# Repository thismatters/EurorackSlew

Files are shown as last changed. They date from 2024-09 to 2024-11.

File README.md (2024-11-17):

# Gated Slew

Causes V/Oct signals to gradually change between voltages with either a linear or logrithmic profile, can work on upward changes in voltage, downward, or both. Slew rate is set with knob. Gate controls whether slew is applied or not.

The circuit here is based on the [Yusynth gated slew](https://yusynth.net/Modular/EN/DUALSLEW/index.html) with minor tweaks to make it more Eurorack friendly. The changes I've made are thus:
* Selected resistors appropriate for +/-12V rails,
* Added polarity protection so that a backward power header doesn't fry anything (twin series schotty diodes: BAT54SL),
* Full surface mount design.

The Yusynth page is a treasure trove of information about this circuit that I am too amateur to claim as my own; please read that outstanding page before using this circuit. The page provides many details and other implementations of this circuit that you may find suitable.

The KiCAD project here uses the library/footprints [found in my companion repo](https://github.com/thismatters/EurorackKiCAD).

## Width

12hp on an Intellijel 1U rack.

## Inputs

Jacks for:
- V/Oct which will be slewed,
- Gate to control when slew occurs (default is always).

Knob for slew rate.

Switches for
- Linear or logrithmic slew,
- Slew on rising edge (up), falling edge (down), or both (middle).

## Outputs

Jack for V/Oct.

LED to indicate when gate is active.

## Vendors

There are part numbers in the [BOM](slew.csv) for many of the parts (not for basic passives though) at the following vendors:

* [Mouser](https://www.mouser.com): Needs no introduction. Get your ICs from here (or [digikey](https://www.digikey.com)).
* [Tayda Electronics](https://www.taydaelectronics.com/): Good supplier for passive components; audio jacks, and potentiometers. Their audio jacks are slightly smaller than the thonkiconn from thonk.
* [Love My Switches](https://lovemyswitches.com/): Has [really good knobs](https://lovemyswitches.com/anodized-aluminum-knob-the-lo-fi-1-4-smooth-shaft-12-5mm-od/) to go on those potentiometers!
* [OSHPark](https://oshpark.com/): Fast and (relatively) cheap PCB manufacturer. The [V0 circuit](https://oshpark.com/shared_projects/VN6XGUSn) works really well.

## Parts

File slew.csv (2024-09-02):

# | Reference | Qty | Value | Footprint | DNP | Vendor | PartNum
1 | C1, C2 | 2 | 22u 50V | Capacitor_THT:CP_Radial_D5.0mm_P2.50mm
2 | C3 | 1 | 100n | Capacitor_SMD:C_0805_2012Metric
3 | C4 | 1 | 680n box | Capacitor_THT:C_Rect_L7.2mm_W4.5mm_P5.00mm_FKS2_FKP2_MKS2_MKP2
4 | D1, D2 | 2 | BAT54S | Package_TO_SOT_SMD:SOT-23 |  | Mouser | 863-BAT54SLT1G
5 | D3, D4, D5, D6 | 4 | 1N4148 | Diode_SMD:D_SOD-323_HandSoldering
6 | D7 | 1 | LED_GREEN | LED_THT:LED_D3.0mm
7 | J1 | 1 | Conn_02x05_Odd_Even | Eurorack:PinHeader_2x05_P2.54mm_Vertical |  | Tayda | A-2939
8 | J2, J3, J4 | 3 | AudioJack2_SwitchT | Eurorack:AudioJack2_Tayda_A-2566 |  | Tayda | A-2566
9 | Q1 | 1 | MMBF4393 | Package_TO_SOT_SMD:SOT-23 |  | Mouser | 863-MMBF4393LT1G
10 | Q2 | 1 | MMBF170 | Package_TO_SOT_SMD:SOT-23 |  | Mouser | 863-MMBF170LT1G
11 | R1, R2, R5 | 3 | 10 | Resistor_SMD:R_0805_2012Metric
12 | R3, R8, R10 | 3 | 120K | Resistor_SMD:R_0805_2012Metric
13 | R4 | 1 | 1M | Resistor_SMD:R_0805_2012Metric
14 | R6 | 1 | 470 | Resistor_SMD:R_0805_2012Metric
15 | R7 | 1 | 2.2M | Resistor_SMD:R_0805_2012Metric
16 | R9 | 1 | 12K | Resistor_SMD:R_0805_2012Metric
17 | R11 | 1 | 1K | Resistor_SMD:R_0805_2012Metric
18 | RV1 | 1 | A1M | Eurorack:Potentiometer_RV16AF-41-15R1 |  | Tayda | A-2425
19 | SW1 | 1 | SW_DPDT_x2 | Eurorack:Switch_DPDT_Tayda_A-5752 |  | Tayda | A-6809
20 | SW2 | 1 | SW_SPDT_MSM | Eurorack:Switch_SPDT_Tayda_A-5751 |  | Tayda | A-5671
21 | U1 | 1 | TL074 | Package_SO:SOIC-14_3.9x8.7mm_P1.27mm |  | Mouser | 595-TL074CDR

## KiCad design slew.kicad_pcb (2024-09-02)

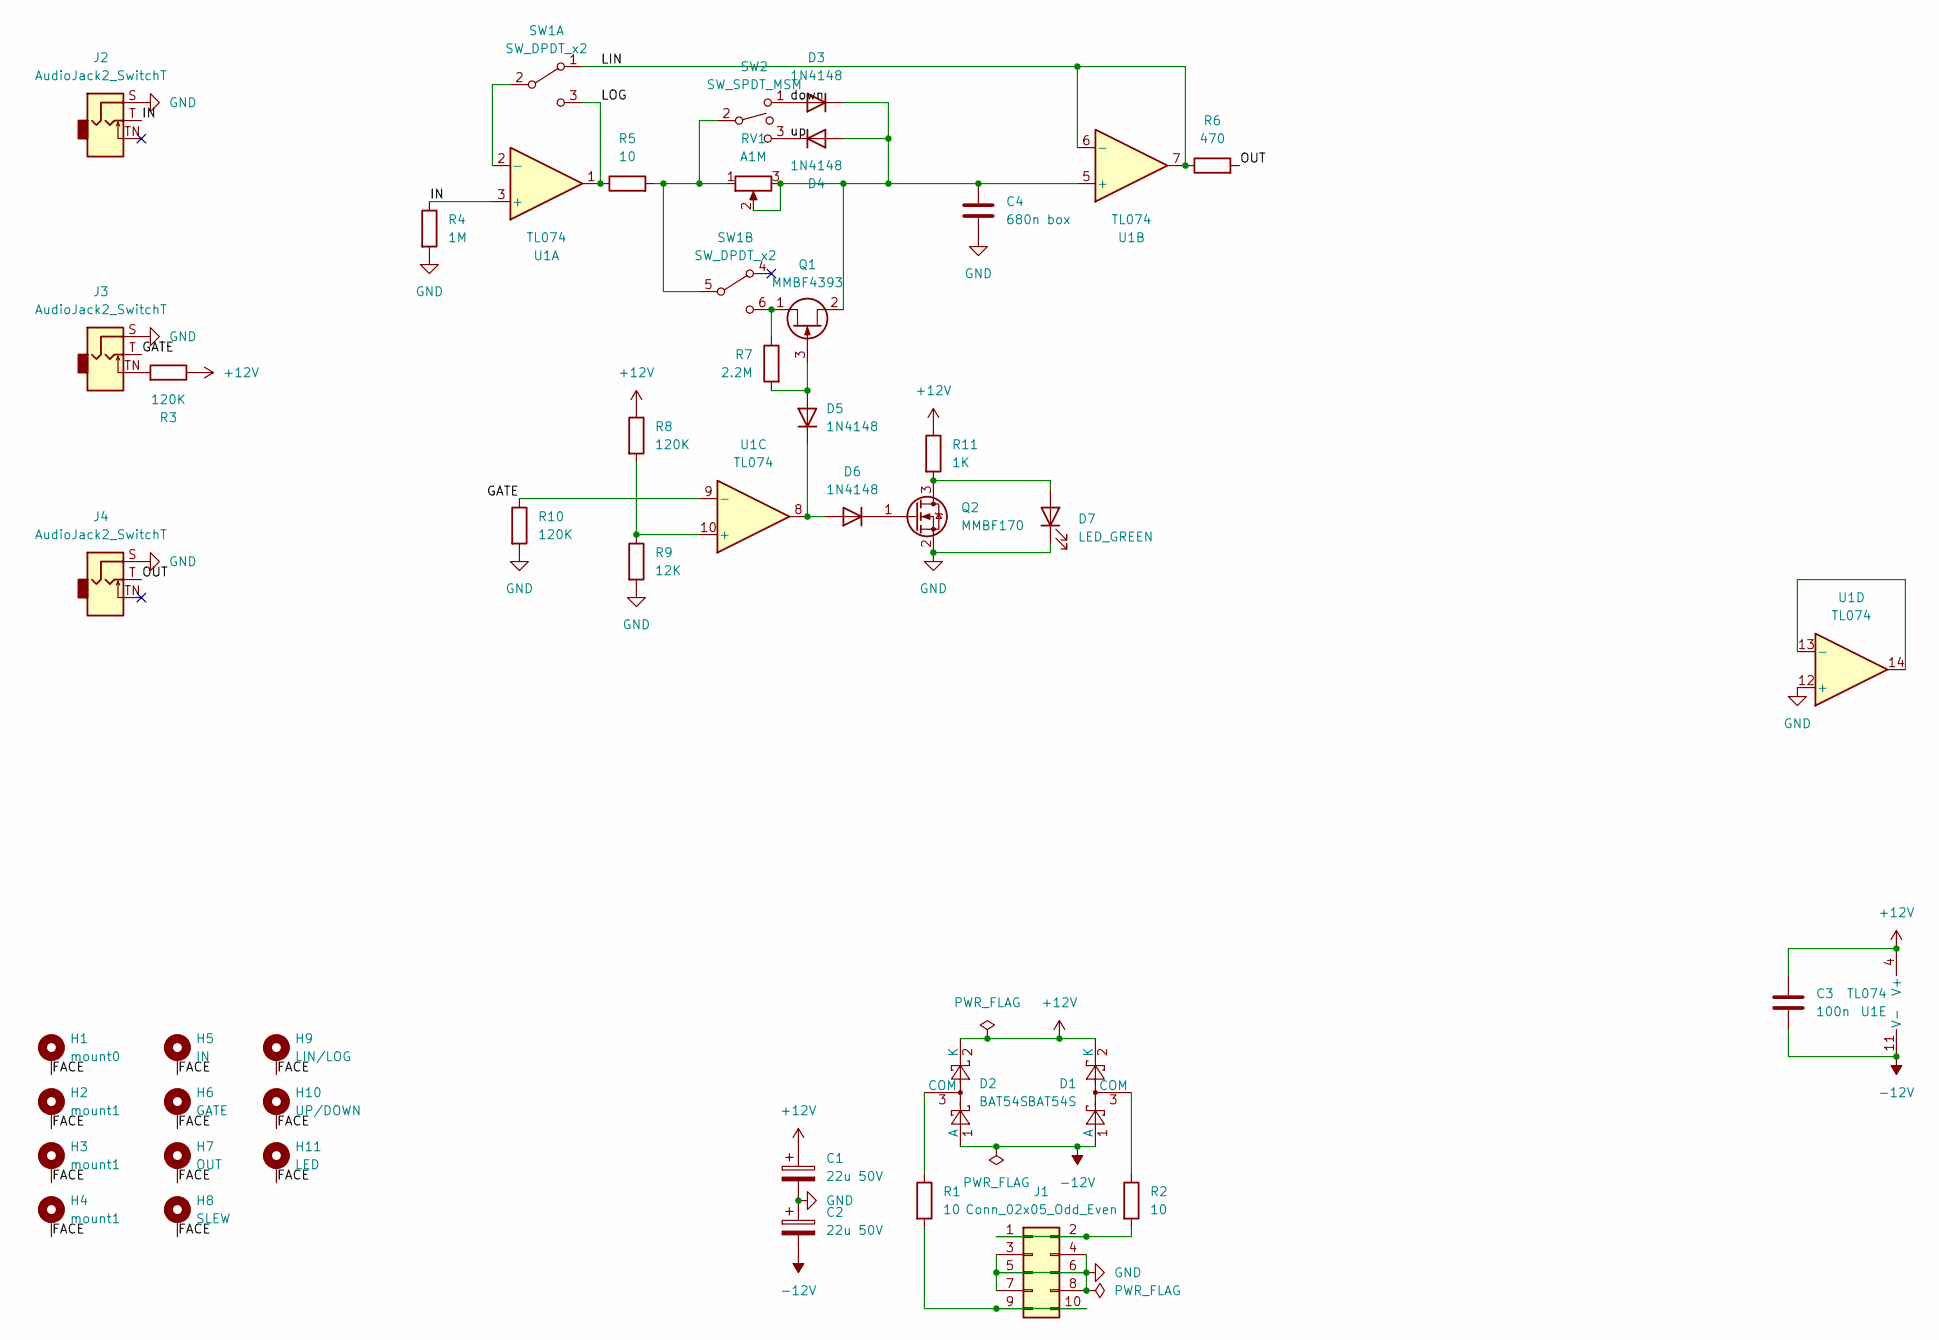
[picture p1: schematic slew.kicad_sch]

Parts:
C1, C2: 22u 50V; CP_Radial_D5.0mm_P2.50mm
C3: 100n; C_0805_2012Metric
C4: 680n box; C_Rect_L7.2mm_W4.5mm_P5.00mm_FKS2_FKP2_MKS2_MKP2
D1, D2: BAT54S; SOT-23; PartNum 863-BAT54SLT1G
D3, D4, D5, D6: 1N4148; D_SOD-323_HandSoldering
D7: LED_GREEN; LED_D3.0mm
H1: mount0; Mech-MountingHole
H2, H3, H4: mount1; Mech-MountingHole
H5: IN; Mech-AudioJack-Hole-Input-Voct
H6: GATE; Mech-AudioJack-Hole-Input-Gate
H7: OUT; Mech-AudioJack-Hole-Output-Voct
H8: SLEW; Mech-Potentiometer-Hole_level_90deg
H9: LIN/LOG; Mech-2M_Switch-Hole
H10: UP/DOWN; Mech-2M_Switch-Hole
H11: LED; Mech-LED-Hole-3mm-Bezel
J1: Conn_02x05_Odd_Even; PinHeader_2x05_P2.54mm_Vertical; PartNum A-2939
J2, J3, J4: AudioJack2_SwitchT; AudioJack2_Tayda_A-2566; PartNum A-2566
Q1: MMBF4393; SOT-23; PartNum 863-MMBF4393LT1G
Q2: MMBF170; SOT-23; PartNum 863-MMBF170LT1G
R1, R2, R5: 10; R_0805_2012Metric
R3, R8, R10: 120K; R_0805_2012Metric
R4: 1M; R_0805_2012Metric
R6: 470; R_0805_2012Metric
R7: 2.2M; R_0805_2012Metric
R9: 12K; R_0805_2012Metric
R11: 1K; R_0805_2012Metric
RV1: A1M; Potentiometer_RV16AF-41-15R1; PartNum A-2425
SW1: SW_DPDT_x2; Switch_DPDT_Tayda_A-5752; PartNum A-6809
SW2: SW_SPDT_MSM; Switch_SPDT_Tayda_A-5751; PartNum A-5671
U1: TL074; SOIC-14_3.9x8.7mm_P1.27mm; PartNum 595-TL074CDR

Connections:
+12V: C1.1, C3.1, D1.2 (K), D2.2 (K), R3.1, R8.1, R11.1, U1.4 (V+)
-12V: C2.2, C3.2, D1.1 (A), D2.1 (A), U1.11 (V-)
/FACE: H1.1, H2.1, H3.1, H4.1, H5.1, H6.1, H7.1, H8.1, H9.1, H10.1, H11.1
/GATE: J3.T, R10.1, U1.9 (-)
/IN: J2.T, R4.1, U1.3 (+)
/LIN: R6.1, SW1.1 (A), U1.6 (-), U1.7
/LOG: R5.1, SW1.3 (C), U1.1
/OUT: J4.T, R6.2
/down: D3.2 (A), SW2.1
/up: D4.1 (K), SW2.3
GND: C1.2, C2.1, C4.2, D7.1 (K), J1.3, J1.4, J1.5, J1.6, J1.7, J1.8, J2.S, J3.S, J4.S, Q2.2 (S), R4.2, R9.2, R10.2, U1.12 (+)
unnamed: D1.3 (COM), R2.1
unnamed: D2.3 (COM), R1.1
unnamed: C4.1, D3.1 (K), D4.2 (A), Q1.2 (S), RV1.2, RV1.3, U1.5 (+)
unnamed: D5.2 (A), Q1.3 (G), R7.2
unnamed: D5.1 (K), D6.2 (A), U1.8
unnamed: D6.1 (K), Q2.1 (G)
unnamed: D7.2 (A), Q2.3 (D), R11.2
unnamed: J1.1, J1.2, R2.2
unnamed: J1.9, J1.10, R1.2
unnamed: J3.TN, R3.2
unnamed: Q1.1 (D), R7.1, SW1.6 (C)
unnamed: SW1.2 (B), U1.2 (-)
unnamed: R5.2, RV1.1, SW1.5 (B), SW2.2
unnamed: R8.2, R9.1, U1.10 (+)
unnamed: U1.13 (-), U1.14

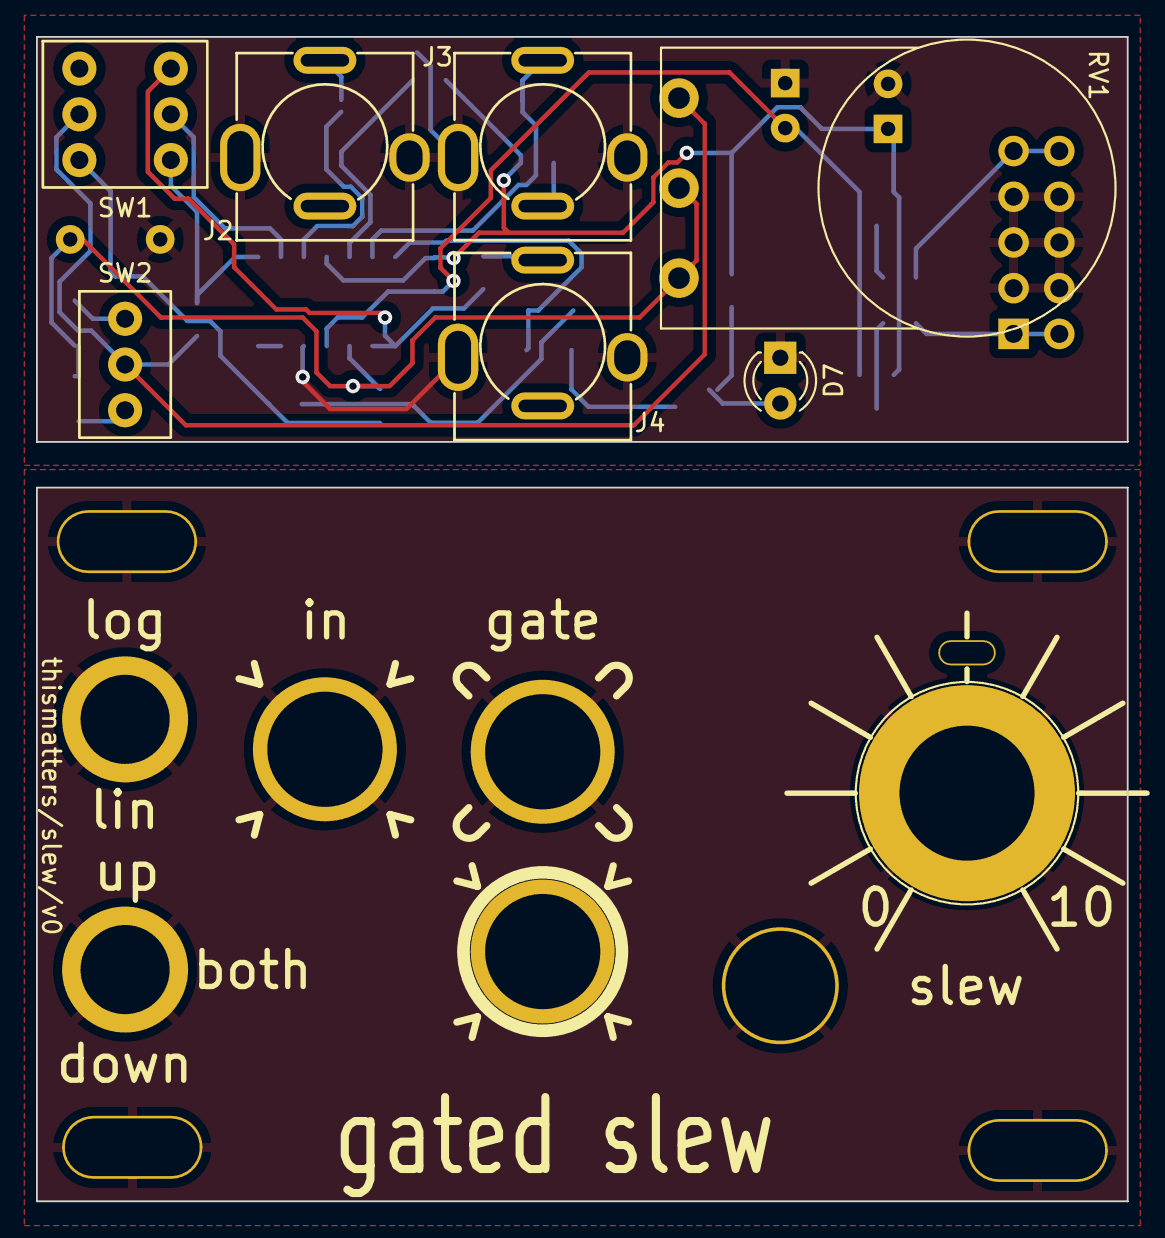
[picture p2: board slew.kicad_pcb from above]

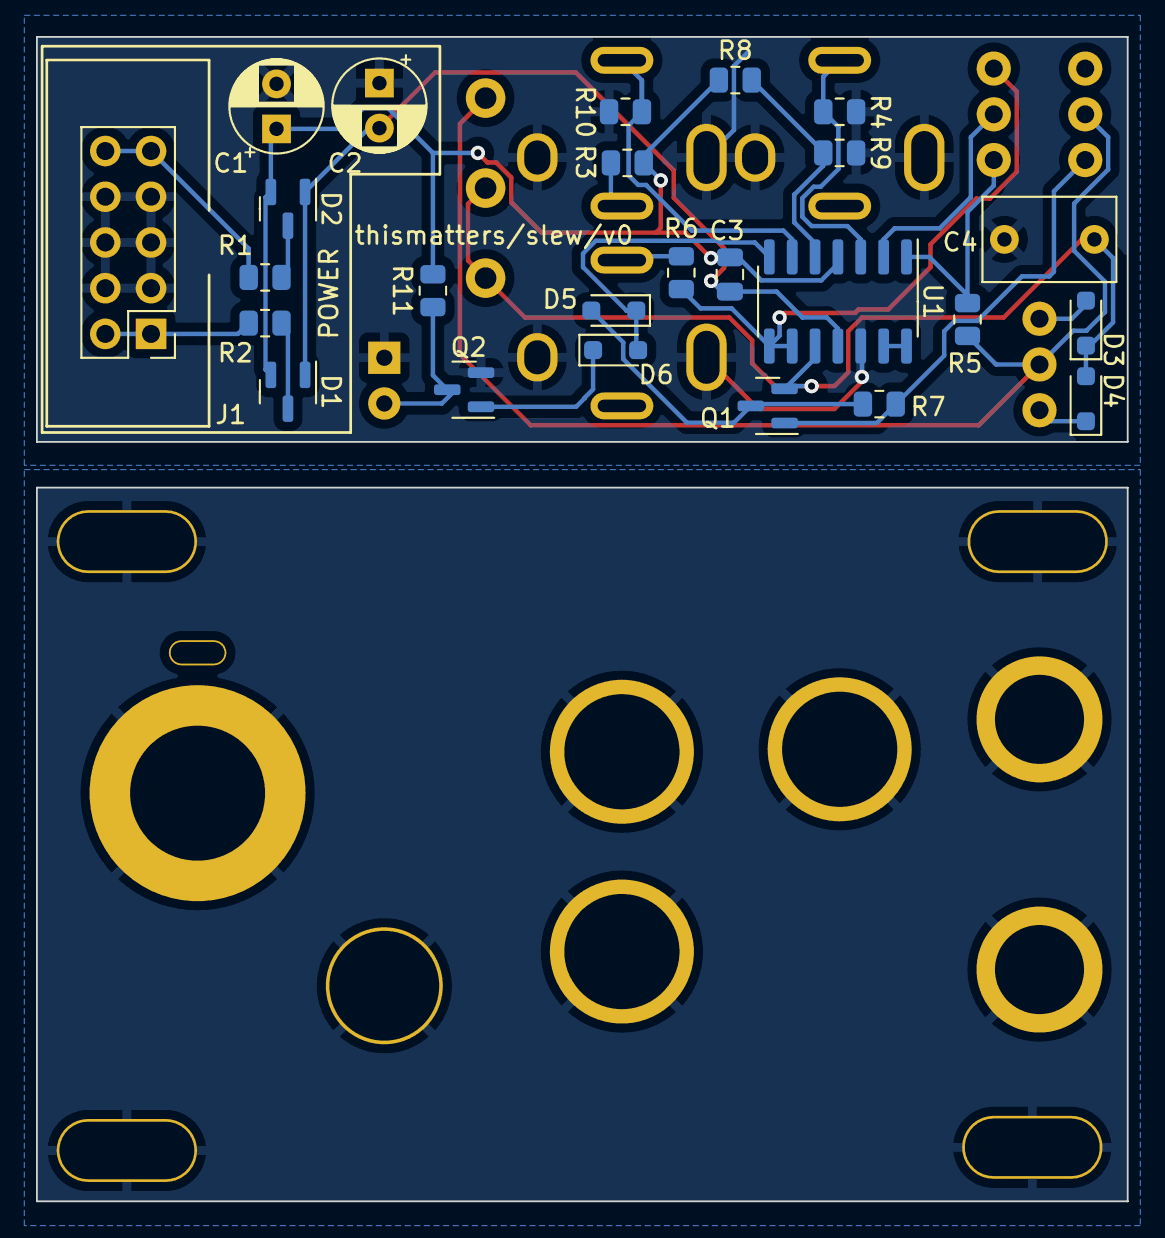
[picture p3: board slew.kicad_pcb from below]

Board: 2 copper layers, 60.6 x 64.7 mm, 43 parts (25 on the bottom side), 26 nets.
